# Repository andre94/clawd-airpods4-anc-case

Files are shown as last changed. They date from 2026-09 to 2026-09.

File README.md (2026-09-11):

# Clawd AirPods 4 ANC Case

**Open, editable CAD for a Clawd-inspired protective cover — not just an STL.**

[Italiano](docs/README.it.md) · [Print files](exports/v04-bottom-access/) ·
[Editable Blender source](models/clawd-airpods4-anc-v04-bottom-access.blend) ·
[Build from source](docs/BUILD.md) · [Licenses and credits](LICENSE.md)

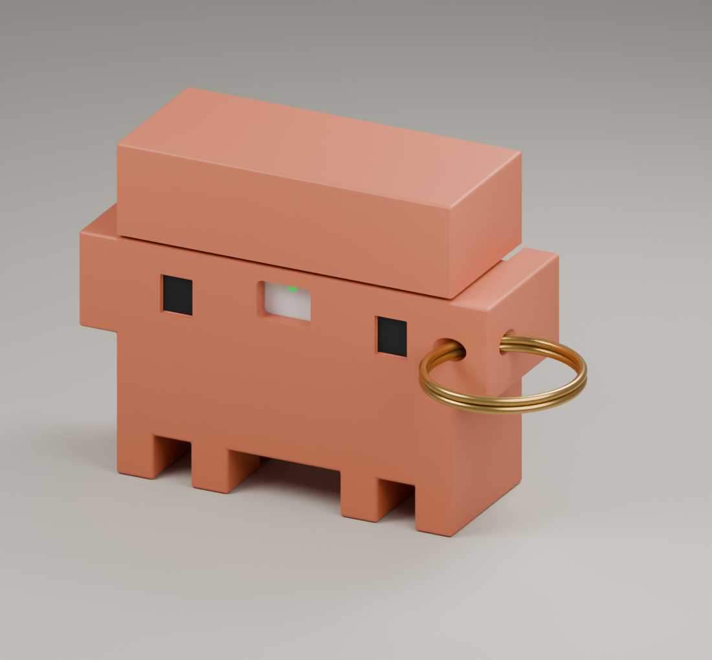
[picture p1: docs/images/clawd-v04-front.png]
Illustrative v04 render with terracotta finish and a reference metal split ring


> **v04-bottom-access — WORK IN PROGRESS.** No physical print or
> actual-device fit test has been completed. Digital mesh and surrogate
> clearance checks are not proof of fit, retention, charging performance or
> keyring strength. Do not treat this as a production-ready product or trust
> an untested cover to carry your AirPods. [Qualification checklist →](docs/QUALIFICATION.md)

v04 adds fuller wrap-around coverage and **five seats for separate soft retention
pads**. The pads are required trial hardware, not printed parts. Bare rigid shells
remain unretained. [Changes, pad guidance and digital checks →](docs/clawd-design-v04.md)

**11 September 2026 update:** removed the two bottom bridges between USB-C and
the side service windows. The lid and all other mesh geometry are unchanged.
Use the `v04-bottom-access` downloads, not the historical v03/v04 exports.
The `v0.4.0-alpha` tag remains the earlier baseline; no new release tag is created.
[Bottom-access changes and checks →](docs/clawd-bottom-access.md)

## Project links

Publication record for **11 September 2026**. The three website updates were
saved and their current file lists or active viewer checked after reloading:

| Platform | Link | Status and contents |
| --- | --- | --- |
| GitHub | [Source repository](https://github.com/andre94/clawd-airpods4-anc-case) | Public; canonical editable CAD, scripts and documentation. |
| GitHub Releases | [Releases and prereleases](https://github.com/andre94/clawd-airpods4-anc-case/releases) | v0.4.0-alpha is the original baseline, before the bottom-access update on main. Earlier releases remain historical artifacts. |
| Printables | [Model files](https://www.printables.com/model/1837773-clawd-airpods-4-anc-case-open-cad-v04-wip/files) | Published v04-bottom-access: two STLs, two-object 3MF and editable Blender file. Old downloads replaced; gallery renders kept. |
| Sketchfab | [Interactive 3D viewer](https://sketchfab.com/3d-models/clawd-airpods-4-anc-case-open-cad-v04-wip-1aea2f19414b48d38c48bbdb90f80ad6) | New bottom-access GLB activated. Downloadable visualization, not a print file. |
| Thingiverse | [Model files](https://www.thingiverse.com/thing:7407403/files) | Saved v04-bottom-access: two STLs, two-object 3MF and source ZIP. Displays the Work in Progress banner, not an unpublished-draft banner. |

Publication does not mean physical validation. Existing gallery renders were
kept; they do not show the underside change. Original v03/v04 files remain in
Git history and their versioned repository folders, not the current site downloads.

## What it is

A two-piece, removable outer cover for the **existing AirPods 4 with Active
Noise Cancellation charging case**. It is not a replacement charging case,
electronics project or certified protective accessory.

- Clawd-inspired blocky body, four legs and recessed eyes.
- Separate slip-on body and lid; no positive device or lid lock is claimed.
- Rear `andreabalbo.com` pixel engraving, nominally 1.0 mm deep.
- A rounded, diagonal Ø4 mm bore on the viewer-right block for a metal split ring.
- Fuller rear wrapping with shaped hinge relief, a bounded front window,
  and joined USB-C / side service openings.
- Five compliant-pad seats: two body sides, two lid sides and one lid roof.
- Terracotta/orange with black eyes is a finish reference, not a matched material color.

Only the **two plastic parts** are print deliverables. The AirPods model, eye
paint previews, pad previews, metal ring, floor, cutters and source assets must not be printed.
The ring shown is illustrative; no hardware is included or specified as load-rated.

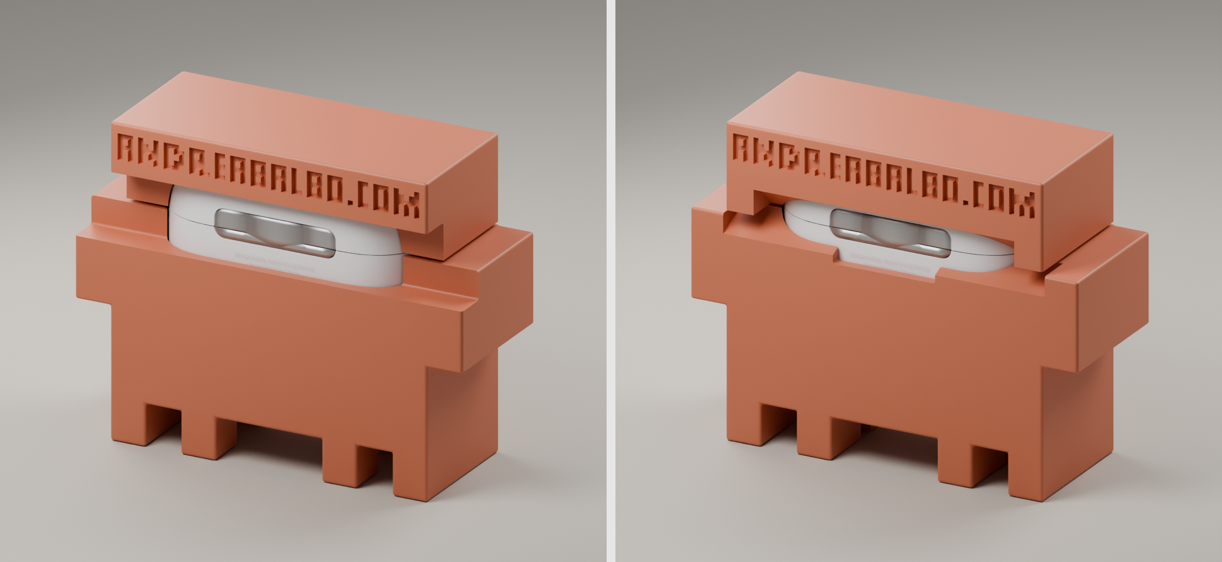
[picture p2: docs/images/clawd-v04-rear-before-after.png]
v03 on the left and v04 on the right, showing fuller rear coverage with hinge clearance


All gallery images are CAD renders, not photographs of a tested print.

## Start here

1. Read [PRINTING.md](docs/PRINTING.md) before paying for a print.
2. Download **one body + one lid** from `exports/v04-bottom-access/`.
   Use **either the two STLs or the two-part 3MF**, not both sets.
3. Select millimetres and 100% scale. Ask your printer to review walls, cavity
   tolerance, engraving and keyring geometry for its specific process.
4. Obtain separate compliant pads. The initial 0.80 mm soft-foam trial thickness
   must be tuned and tested; neither retention force nor adhesive safety is qualified.
5. Print an unpainted prototype first. Validate it on the real device before
   paying for color finishing or treating it as a usable carrying accessory.

| Item | Nominal CAD dimensions, mm |
| --- | --- |
| Body STL | 75.78 × 26.90 × 42.40 |
| Lid STL | 62.00 × 26.90 × 16.50 |
| Closed plastic assembly, excluding hardware | 75.78 × 26.90 × 59.60 |
| Cavity clearance relative to visual surrogate | 0.35 normal offset |
| Local pad-seat normal gap relative to surrogate | 0.65 |
| Keyring bore | Ø4.00 |

Dimensions are CAD values, not measured finished parts or toleranced drawings.
The 3MF contains meshes and explicit millimetre units, **not a validated printer profile**.

## Source and remixing

Open `models/clawd-airpods4-anc-v04-bottom-access.blend` in Blender **5.2.1 LTS**
(the version used for this update). The file retains print parts, masters, cutters, fit-check
parts, credited visual references and presentation objects in named collections.
One Blender coordinate unit represents 1 mm; scene `scale_length` is 0.001.

The Python construction history and JSON parameters are included. A clean
rebuild needs Blender and Python, not Codex, Claude Code or a running MCP server:

```sh
python3 tools/rebuild.py --blender /path/to/blender --output /path/to/new-empty-build
/path/to/blender --background /path/to/new-empty-build/models/clawd-airpods4-anc-v04.blend \
  --python-exit-code 1 --python /path/to/new-empty-build/tools/export_clawd_bottom_access.py
```

The first command rebuilds the original v04 baseline; the second applies and
exports the approved bottom-access update in that new build directory.
See [BUILD.md](docs/BUILD.md) for the construction-stage dependencies,
supported lettering and reproducibility limits. Editing JSON does **not** update
the already-exported meshes automatically. Regenerate and revalidate changes.

## Contribute

Useful contributions include measured-device fit reports, printer/process
tolerance results, non-destructive retention improvements, keyring testing,
lettering improvements and accessible printing instructions. Use the issue
templates and [contribution guide](CONTRIBUTING.md). Failed prototypes are useful
data when material, process, scale and exact revision are recorded.

Please do not upload restricted reference assets, proprietary CAD, personal
shipping details, supplier correspondence or someone else's unlicensed designs.

## Open licensing and attribution

- **CAD, parameters, documentation and renders:** CC BY-SA 4.0 for our contributions.
- **Python tools and CI:** MIT.
- **Original Clawd and AirPods source assets:** CC BY 4.0, with author credits.

Both project licenses permit commercial reuse under their terms. That does not
grant trademark or endorsement rights. This is **unofficial fan work**, not an
Apple or Anthropic product. Read [LICENSE.md](LICENSE.md) and preserve
[THIRD_PARTY_NOTICES.md](THIRD_PARTY_NOTICES.md), including the credits to
**akmiller01** and **Falah3D**. Non-open donor-case files are excluded from this
repository, the public blend and the rebuild dependencies.

Designed by [Andrea Balbo](https://andreabalbo.com), with AI-assisted Blender
scripting and modelling. Geometry checks are automated; physical validation is
still a human, real-device task. The license does not provide a warranty.

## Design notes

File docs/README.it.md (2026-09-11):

# Clawd AirPods 4 ANC Case

Custodia protettiva esterna, in due parti, per il case di ricarica **AirPods 4
con ANC**. È un progetto fan-made ispirato a Clawd, non un prodotto Apple o
Anthropic e non un sostituto del case elettronico originale.

**v04-bottom-access: prototipo non ancora verificato fisicamente.** I controlli
digitali non garantiscono dimensioni finite, tenuta del coperchio, ricarica o
resistenza del foro. Non affidargli il trasporto degli AirPods prima delle prove.

Aggiornamento dell'11 settembre 2026: rimossi i due ponti inferiori tra USB-C e
le finestre laterali. Coperchio e tutte le altre geometrie restano invariati.
Il tag `v0.4.0-alpha` conserva la versione precedente; non viene creato un nuovo
tag. [Modifiche e controlli](clawd-bottom-access.md).

## Link del progetto

Registro dell'**11 settembre 2026**: aggiornamenti salvati e verificati sulle
tre piattaforme, con nuovi file `v04-bottom-access` e rendering esistenti mantenuti.

| Piattaforma | Link | Stato e contenuti |
| --- | --- | --- |
| GitHub | [Repository sorgenti](https://github.com/andre94/clawd-airpods4-anc-case) | Pubblico; CAD modificabile, script e documentazione di riferimento. |
| GitHub Releases | [Release e prerelease](https://github.com/andre94/clawd-airpods4-anc-case/releases) | v0.4.0-alpha resta la versione precedente, prima dell'aggiornamento su main. |
| Printables | [File del modello](https://www.printables.com/model/1837773-clawd-airpods-4-anc-case-open-cad-v04-wip/files) | Pubblicati due STL, 3MF e Blender aggiornati; vecchi download sostituiti. |
| Sketchfab | [Visualizzatore 3D interattivo](https://sketchfab.com/3d-models/clawd-airpods-4-anc-case-open-cad-v04-wip-1aea2f19414b48d38c48bbdb90f80ad6) | Nuovo GLB attivato. Non è un file per la stampa. |
| Thingiverse | [File del modello](https://www.thingiverse.com/thing:7407403/files) | Salvati due STL, 3MF e ZIP sorgenti aggiornati. La pagina mostra Work in Progress, non il banner di bozza non pubblicata. |

La pubblicazione non equivale a una verifica fisica. I rendering esistenti non
mostrano la modifica inferiore. Le versioni precedenti restano nello storico Git.

## Cosa scaricare

- Un corpo e un coperchio da `exports/v04-bottom-access/`.
- Scegliere i due STL **oppure** il 3MF contenente entrambi: non stampare duplicati.
- Unità millimetri, scala 100%. Il 3MF non contiene un profilo macchina validato.
- Il file Blender modificabile è in `models/`; parametri e script sono inclusi.

Corpo: circa **75,78 × 26,90 × 42,40 mm**; coperchio: **62 × 26,90 × 16,50 mm**.
Il foro portachiavi diagonale ha diametro nominale 4 mm. L'incisione
`andreabalbo.com` è profonda nominalmente 1 mm. Dispositivo e anello nei rendering
sono riferimenti visivi, non pezzi da stampare.

## Novità v04 e ritenzione

Maggiore copertura posteriore con scarico sagomato per la cerniera, finestra
frontale delimitata e aperture USB-C/laterali ora collegate. Non è una
custodia sigillata o impermeabile. Sagoma, incisione e foro restano invariati.

Servono **cinque inserti morbidi separati**, non stampati: due sul corpo, due
ai lati del coperchio e uno nel tetto. Le sedi hanno un gioco normale nominale
di 0,65 mm. Schiuma di silicone morbida da 0,80 mm è solo uno spessore iniziale
da provare, non una specifica verificata. Senza inserti i gusci rigidi restano
privi di ritenzione. Se necessario, valutare un inserto biadesivo rimovibile nel
tetto, dopo aver verificato compatibilità e rimozione; niente colla permanente.

Il controllo digitale di 116 posizioni da 0 a 115° non rileva collisioni con il
simulacro e gli inserti illustrativi. **Non è una prova fisica di apertura senza
attrito né di tenuta.** [Dettagli v04](clawd-design-v04.md).

## Come procedere

Prima un prototipo non verniciato, poi eventuali correzioni e finitura colorata.
Far valutare al fornitore materiale, spessori, tolleranze finite e resistenza
dell'attacco. Il PA12 non caricato MJF/SLS è un candidato da valutare, non una
specifica già qualificata. FDM, resina e TPU non sono automaticamente equivalenti.

Verificare sul dispositivo reale inserimento, rimozione, ritenzione, apertura,
accesso USB-C, altoparlante, comandi e ricarica. Il foro sostiene soltanto il corpo
esterno: **non blocca il case AirPods né il coperchio della cover**. Per le prove
di trazione usare prima un guscio vuoto o un simulacro, non gli AirPods.

Guide: [stampa](PRINTING.md), [prove fisiche](QUALIFICATION.md),
[ricostruzione da sorgenti](BUILD.md), [contributi](../CONTRIBUTING.md).

## Licenze

CAD, parametri, documentazione e rendering originali/adattati: **CC BY-SA 4.0**.
Script e workflow: **MIT**. Gli asset originali di akmiller01 e Falah3D conservano
**CC BY 4.0**, con attribuzione. Le licenze ammettono anche riuso commerciale alle
loro condizioni, ma non attribuiscono diritti sui marchi né implicano approvazione
dei produttori. Leggere [licenze](../LICENSE.md) e
[crediti completi](../THIRD_PARTY_NOTICES.md).

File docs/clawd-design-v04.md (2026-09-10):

# Clawd AirPods 4 ANC — v04 coverage and pad-retention prototype

10 September 2026. **Unvalidated physical prototype, not a production release.**

## Decision

The concern about the separate top cap is justified: v03 had a nominal
0.35 mm clearance cavity, a broad rear opening and no defined retention
hardware. Covering more of the device improves enclosure and provides more
supported contact area, but adding rigid material alone does not create grip.

The linked [Spigen Rugged Armor listing](https://www.amazon.it/dp/B0BC2B91VF),
checked on 10 September 2026, describes a two-piece **TPU** cover for **AirPods
Pro 2**, not a rigid PA12 cover for AirPods 4. Its fuller coverage is a useful
reference, but its dimensions and flexible fit cannot be copied directly.
The Clawd target remains **AirPods 4 with ANC**, using the existing calibrated
50.1 × 21.2 × 46.2 mm visual surrogate, not measured OEM CAD.

v04 keeps the two-shell architecture and the stock device hinge. It adds
fuller wrap-around coverage and deliberately specifies separate soft pads
instead of pretending that a loose hard-plastic cap will retain itself.

## Geometry changes

| Feature | v04 change |
| --- | --- |
| Lid | Extends the rear skirt outside the local hinge region; front, roof and side coverage remain |
| Rear body | Restores material outside the local hinge window, then clears the actual planned opening motion |
| Rear hinge window | 20 mm central construction width instead of a full-width cut; additional shaped motion clearance remains |
| Front | Bounded 10 × 7 mm rounded LED/pairing window, centred at Z 28.3 mm; a solid bridge now runs above it |
| Bottom | 14 × 8 mm USB-C window and two 6 × 4 mm speaker-access windows at X ±13 mm, replacing the 36 × 10 mm opening |
| Lid retention | Two side-pad seats plus one 16 × 7 mm roof-pad seat |
| Body retention | Two side-pad seats |
| Preserved | Clawd silhouette, eye recesses, 1 mm pixel branding, 4 mm diagonal keyring bore, nominal device calibration and 0.70 mm seam gap |

The rigid lid cannot extend uninterrupted across the entire rear seam: that
material would sweep into the charging-case body when opened. The rear cap
relief is derived from a 0.45 mm-expanded body envelope swept into lid
coordinates. Each section is clipped to the relevant rear region before
convex enclosure, avoiding an unnecessarily large cut across the cap. The
outer body is also relieved for the rear skirt. Construction samples are
0.5 degrees apart; verification separately checks 116 poses at 1-degree steps.

**This is fuller coverage, not a completely sealed case.** Functional hinge,
LED/tap, USB-C and speaker openings remain. No waterproof or impact rating is
claimed. The service windows are provisional and must be checked on the real
AirPods and charging cable; matching a visual asset does not validate access.

The closed printed envelope is unchanged. The body remains approximately
75.778 × 26.900 × 42.396 mm and the lid 62.000 × 26.900 × 16.504 mm.
Body and lid heights are separate part bounding boxes, not the assembled height.

## Retention pads — required, not printed

The cavities outside the seats retain the v03 nominal 0.35 mm clearance. The
seats use a nominal 0.65 mm normal offset, approximately 0.30 mm deeper than
the original cavity, to accommodate compliant pads. **Without pads, these
recesses do not improve grip and the bare shells remain unretained.**

| Seat | Quantity | Nominal footprint / position |
| --- | --- | --- |
| Body side | 2 | 8 mm in Y × 8 mm in Z; Z 18–26 mm |
| Lid side | 2 | 8 mm in Y × 5 mm in Z; Z 39.2–44.2 mm |
| Lid roof | 1 | 16 mm in X × 7 mm in Y; follows the inner roof contour |

Use supplier-approved, soft, non-marking silicone foam or equivalent compliant
material. **0.80 mm uncompressed thickness is an initial sample, not a finished
fit specification.** It suggests roughly 0.15 mm compression against a nominal
0.65 mm normal gap, but local curvature, adhesive backing, material behaviour,
device geometry and print tolerances all change the result. Footprints are
projected design dimensions, not flattened cutting patterns for curved pads.

Pads initially bond to the cover and grip the device by friction. If a physical
test shows insufficient lid retention, the roof seat can accommodate a
finish-compatible **removable double-sided pad**. Qualify its removability and
surface compatibility first; do not use permanent glue or force the device in.
There is no rigid snap feature against the unmeasured Apple seam, no latch,
no retention-force prediction and no secure-carrying claim.

The five charcoal objects in the Blender file are illustrative seated pad
envelopes with a small display clearance. They are **not uncompressed foam
CAD, print parts or a deformation simulation**. The two metal ring coils are
also display-only. Print exports contain only the two rigid shells.

## Digital checks

- Both final print meshes are closed, single-component and consistently
  oriented, with positive volumes, no loose geometry, no non-manifold edges
  and no non-adjacent triangle-overlap candidates in the mesh screen.
- Closed shell/device intersection volumes pass, as do 66 sampled axial
  insertion positions per rigid shell. Insertion with real compressed pads
  is not simulated.
- The dense motion screen checks 0–115 degrees inclusive at 1-degree steps,
  including the rigid lid and seated pad previews against the body, body-pad
  previews, charging-case body surrogate and positioned reference ring.
  It reports no surface collisions. Real hinge geometry, continuous motion,
  elastic behaviour and hardware articulation remain unqualified.
- Nine axis-aligned rays per pad seat give body-side gaps of approximately
  0.650–0.665 mm, lid-side gaps of 0.702–0.822 mm and roof gaps of 0.650–0.662 mm.
  Axis gaps are not normal pad thicknesses. The smallest sampled seat backing
  is approximately **2.100 mm at the roof**; this is not a global wall minimum.
  Measurement uses zero BVH inflation and avoids shared-facet sampling points.
- The v03 insertion cutters, calibration references, branding cutter and
  keyring cutter retain their geometry digests. The new shells reuse them.
- STL round-trip dimensions and topology pass at one coordinate unit per mm.
  The 3MF explicitly declares millimetres and contains exactly two objects.
- All previous `.blend` models and original reference-input hashes are unchanged.
  No external references are reported missing in the saved model.

A separate 0.5 mm orthographic grid screen measures **projected exposed
surrogate area**, excluding pads. It is not total surface coverage or a
protection rating:

| View | v03 exposed area | v04 exposed area | Reduction |
| --- | ---: | ---: | ---: |
| Front | 118.50 mm² | 69.25 mm² | 41.6% |
| Rear | 562.00 mm² | 343.00 mm² | 39.0% |
| Bottom | 359.25 mm² | 158.25 mm² | 55.9% |

## Files and reproduction

- Editable model: `models/clawd-airpods4-anc-v04.blend`.
- Parameters: `models/clawd-v04-parameters.json`.
- Revision builder: `tools/revise_clawd_coverage.py`.
- Render script: `tools/render_clawd_coverage.py`.
- Print prototypes and briefing: `exports/clawd-v04/clawd-prototype/`.
- Machine-readable mesh, export and coverage checks: `exports/clawd-v04/qa/`.
- Release renders: `docs/images/`; the rear comparison is **v03 left,
  v04 right**. `pad-seats` is an exploded, device-hidden view, not an operating
  hinge position. Colour and hardware are illustrative.

Use `tools/rebuild.py` as described in [BUILD.md](BUILD.md) to reconstruct the
entire history without MCP. The v04 builder opens the saved v03 file in a separate
background Blender process. It refuses live interactive scenes, checks millimetre units
and refuses to overwrite an existing v04 unless its exact expected SHA-256 is
supplied. It preserves archived v03 shells inside the new file. The old fit-check
pair remains historical context and is **not** a v04 pad-fit coupon or export.

The render script opens v04 in background, regenerates its own presentation
scene and does not save over the editable model. The live Blender bridge was
unavailable during this revision; no live scene or global preferences changed.

## Physical qualification before carrying or ordering

1. Obtain written supplier acceptance for the new files, unfilled MJF PA12,
   finished cavity accuracy, new rear contours, pad seats and service windows.
   Do not scale, automatically thicken or silently repair the model.
2. Print one unpainted pair. Inspect and depowder all openings. Check the actual
   device and cable before adding pads; never force a tight fit.
3. Measure the printed seat gaps and trial compliant pads of suitable thickness.
   Verify device finish compatibility and removal. Excessively thick pads can
   overload the lid hinge or make the case difficult to remove.
4. Test body and cap retention separately, including repeated opening, closing,
   removal and ordinary handling over a soft surface. Qualify any removable roof
   adhesive only if needed. Do not infer retention from the digital mesh check.
5. Check full opening, earbud removal, the LED and pairing/reset taps, USB-C
   connector moulding, ANC speaker audibility and Qi/Apple Watch charging,
   including attachment, alignment and temperature with pads installed.
6. Test the keyring anchor with an empty case or suitable dummy. **Do not carry
   the real AirPods by the ring until body retention, cap retention and anchor
   behaviour have all been physically qualified.** No load rating is provided.

v04 has not been uploaded to a printer, quoted, accepted or ordered.
Earlier v02/v03 quote or automatic acceptance results do not transfer to it.

The public Blender copy removes restricted donor and donor-derived archived
objects without changing the v04 print geometry. `publication-audit.json`
records the unchanged geometry digests; `manifest.json` records public file hashes.
`final-review.json` records the pre-publication working-scene hash, not the
sanitized public Blender file hash. Publication is not physical qualification.

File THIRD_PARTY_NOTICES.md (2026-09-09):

# Third-party notices and provenance

Source pages and license links checked on 9 September 2026. Attribution is not
an assertion that the original uploaders control every depicted brand right.

## Clawd silhouette — akmiller01

- Work: [Simple Claude Code Mascot - Clawd](https://www.printables.com/model/1655582-simple-claude-code-mascot-clawd).
- Author: [akmiller01](https://www.printables.com/@akmiller01_232084).
- License: [Creative Commons Attribution 4.0 International](https://creativecommons.org/licenses/by/4.0/).
- Original included at `assets/reference/clawd.stl` and in the `CLAWD_ORIGINAL`
  collection of the editable assembly.
- Provenance check: the original local file's download-origin URL exactly
  matches the target of the `clawd` STL download button on that model's Files
  page. It is the 6,284-byte file, not the separate `clawd_singlecolor` variant.
- Modifications: extracted and proportionally adapted silhouette, new depth,
  rounded edges, split body/lid, cavity and service cuts, rebuilt eye recesses,
  custom rear lettering and diagonal keyring bore.

## AirPods 4 visual reference — Falah3D

- Work: [AirPods 4](https://sketchfab.com/3d-models/airpods-4-e44730974131402eb496352cab19c82e).
- Author: [Falah3D / 3dFalah](https://sketchfab.com/3dFalah).
- License: [Creative Commons Attribution 4.0 International](https://creativecommons.org/licenses/by/4.0/).
- Original FBX and textures are included under `assets/reference/airpods-4/`;
  imported objects are in `AIRPODS_VISUAL_REFERENCE_NOT_METROLOGY`.
- Identification evidence: matching title, original FBX format, 16 February
  2026 file date, approximately 7 MB source bundle and the published 54.3k
  vertices / 99.2k triangles (local import: 54,281 / 99,248). A fresh archive
  byte-for-byte comparison was not available because the browser blocked its
  download. This identification is documented rather than presented as a
  verified upstream checksum.
- Modifications: close the visual lid pose; calibrate overall dimensions to
  published nominal dimensions; derive convex body/lid envelopes and offset
  cavities; position and re-material selected geometry for illustrative renders.
- This is not Apple engineering CAD, metrology, a fit guarantee or certification.

## Studied but excluded — Generic Makerspace

The private reference study also inspected *Milk Crate Airpods 4 Case* and
*Retro Gameboy Airpods 4 Case* by Generic Makerspace. Both supplied 3MF files
declare **Standard Digital File License**, not an open license.

Those 3MF files, STL archives, extracted donor meshes, reference-study blend,
creator images and slicer profiles are **not included** here. Donor body/lid
objects are removed from the public Blender copy. The public reconstruction
imports only the two CC BY assets above; no donor package is required. The
cover's cavity is derived from the credited AirPods visual reference, not from
the restricted case meshes.

## Tools and brand names

Blender is separately licensed software. Its source, binaries and the Blender
Lab MCP server are not vendored here. The project uses Blender's Python API;
the optional MCP connection is a development convenience, not a build dependency.

Clawd is a Claude Code mascot reference. This is unofficial fan work, not
affiliated with or endorsed by Anthropic or Apple. Project licenses do not
grant rights in their names, trademarks or other rights outside our control.

Suggested credit when sharing an image or adaptation:

> Clawd AirPods 4 ANC Case by Andrea Balbo, CC BY-SA 4.0. Adapted from
> “Simple Claude Code Mascot - Clawd” by akmiller01 (CC BY 4.0); AirPods visual
> reference by Falah3D (CC BY 4.0). Unofficial, physically unvalidated prototype.

Include the source and license links above with that credit, and identify your
own changes. Reference-only hardware and device geometry are not print parts.

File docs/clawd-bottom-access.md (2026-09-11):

# Bottom-access update — 11 September 2026

The `v04-bottom-access` files replace the previous website downloads. The
original `v0.4.0-alpha` tag remains unchanged; this update does not create a tag.

## Geometry

Removed the two narrow body bridges between the USB-C opening and the side
service windows using rounded Boolean cutters:

| Side | Minimum XYZ, mm | Maximum XYZ, mm | Radius, mm |
| --- | --- | --- | --- |
| Left | −11.5, −2, −15 | −5.5, 2, 8 | 0.8 |
| Right | 5.5, −2, −15 | 11.5, 2, 8 | 0.8 |

The cuts overlap the existing windows, joining them without widening the outer
ends. The body envelope, lid and all other mesh geometry remain unchanged.
About 59.597 mm³ of material is removed. The credited visual device model is
not measured OEM CAD; visible access is not proof of real-device alignment.

## Files and checks

- [Current printable pair and GLB](../exports/v04-bottom-access/).
- [Editable source](../models/clawd-airpods4-anc-v04-bottom-access.blend).
- [Patch/export script](../tools/export_clawd_bottom_access.py).
- [Digital validation report](../exports/v04-bottom-access/validation.json).
- [Build instructions](BUILD.md) and [printing guidance](PRINTING.md).

The public source was generated from the sanitized, unanimated v04 baseline.
The body exactly matches the approved local study geometry:
`bb031bed17fe1cbfba8442a1411f668d860277779b1489c44ae3fb4ee46e9959`.
It remains one closed oriented component with positive volume, no loose vertices,
degenerate faces or nonadjacent triangle-overlap candidates. All 18 sampled
vertical rays through the two removed bridges are unobstructed.

Both STLs pass millimetre-scale round-trip checks. The 3MF has two mesh objects
and explicit millimetre units. The viewer has four meshes: body, lid and two
paint indicators; no device, pads, ring or cutters. Its combined glTF-axis bounds
are 75.78 × 59.60 × 26.90 mm.

Existing uploaded gallery renders were kept. The sites may regenerate previews
associated with replaced model files. No actual print or physical test has been
performed: check alignment, cable clearance, acoustics, charging, retention,
finish compatibility and strength before use.

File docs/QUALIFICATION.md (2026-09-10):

# Physical qualification — pending

No real-device or physical-print test has been completed for this release.
The downloaded AirPods visual model is not measured OEM CAD. Published Apple
overall case dimensions (50.1 × 21.2 × 46.2 mm) do not specify local contours,
hinge location, opening forces or manufacturing tolerances.

## Current evidence

- The two release meshes have closed, consistently oriented geometry and one
  connected component each in the recorded digital checks.
- Discrete surrogate-based insertion and hinge sweeps pass the recorded checks.
- v04 passes 116 hinge poses from 0–115° at 1° intervals, including illustrative
  seated pads. This is a collision screen, not proof of frictionless opening,
  real hinge alignment, foam deformation or a continuously swept clearance.
- The keyring envelope check is a geometric screen, not a threading simulation,
  minimum-wall certification, fatigue test or load rating.
- No supplier's approval, physical fit, protective performance, drop resistance,
  wireless charging behavior or hardware retention is established by those checks.

## Record for each prototype

Record exact release/commit and file SHA-256, printer/provider, process, material,
orientation, dimensional settings, finish and any post-processing. Use measured
values when available; mark visual estimates explicitly. Never put addresses,
phone numbers, invoices, order numbers or private correspondence in a public issue.

For v04, also record pad material, uncompressed thickness, adhesive backing,
placement, removability and changes after compression/wear. The five pad seats
and suggested 0.80 mm starting trial do not constitute a tested retention system.

- [ ] Inspect the empty print for sharp edges, loose powder/supports and cracks.
- [ ] Confirm overall dimensions and local clearances; check cavity condition.
- [ ] Trial gentle insertion/removal without force or leverage on connectors.
- [ ] Verify body retention and **separate lid retention** independently.
- [ ] Check pad surface compatibility, compression, adhesive residue and safe
      removal; test a removable roof bond separately if one is needed.
- [ ] Check full lid opening, hold-open behavior and earbud removal by hand.
- [ ] Check the actual USB-C plug without loading the charging port.
- [ ] Verify status LED visibility and pairing/reset front-tap operation.
- [ ] Verify ANC Find My speaker audibility through the cover.
- [ ] Check Qi and Apple Watch charging alignment, attachment and temperature;
      stop on unusual heating, interrupted charging or other abnormal behavior.
- [ ] Check the actual split ring's wire dimensions, threading and articulation
      without scratching or stressing the plastic.
- [ ] Evaluate pull, twist, snag and wear with an **empty cover or dummy first**.
      Do not use valuable electronics for unqualified load or drop tests.
- [ ] Recheck retention after wear, finishing and any removable liner adjustment.

The keyring attaches only to the outer body. It does not lock the AirPods case
inside it or secure the separate cover lid. There is **no rated carrying load**.
Passing one sample does not establish reliability for different materials or
printers. Document failures and revisions rather than silently scaling files.

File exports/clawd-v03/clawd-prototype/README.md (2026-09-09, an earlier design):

# v03 prototype print files — physically unvalidated

Print one body and one lid. Use **either both STLs or the two-part 3MF**; do not
order duplicate parts by uploading all three files. Units are millimetres at
100% scale. The 3MF is mesh-only, not a qualified slicer profile.

- Body: 75.78 × 26.90 × 42.40 mm.
- Lid: 62.00 × 26.90 × 16.50 mm.
- No device, ring, paint or assembly hardware is included.

Read [printing guidance](../../../docs/PRINTING.md) and the
[physical qualification checklist](../../../docs/QUALIFICATION.md) before
ordering. Ask your printer to assess cavity tolerances, thin walls, engraving
and keyring strength. First print unpainted; fit and retention are untested.
An untested cover must not be relied on to carry the device.

CAD adaptations by Andrea Balbo, CC BY-SA 4.0; upstream Clawd by akmiller01 and
AirPods visual reference by Falah3D, CC BY 4.0. Preserve
[third-party notices](../../../THIRD_PARTY_NOTICES.md) and
[license terms](../../../LICENSE.md). Unofficial fan work; no brand rights granted.

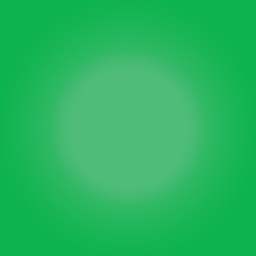
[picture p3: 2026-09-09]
assets/reference/airpods-4/textures/DGBEWepXmsFLatr.png

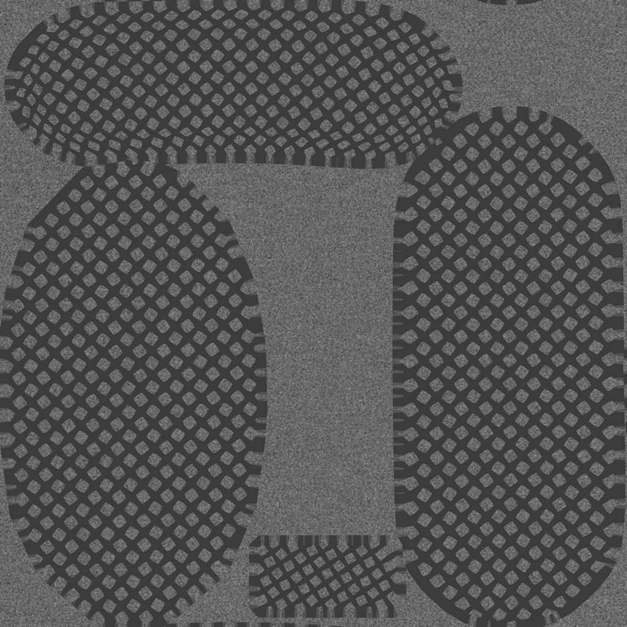
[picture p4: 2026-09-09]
assets/reference/airpods-4/textures/hzRAhqrsyMepKLY.jpg

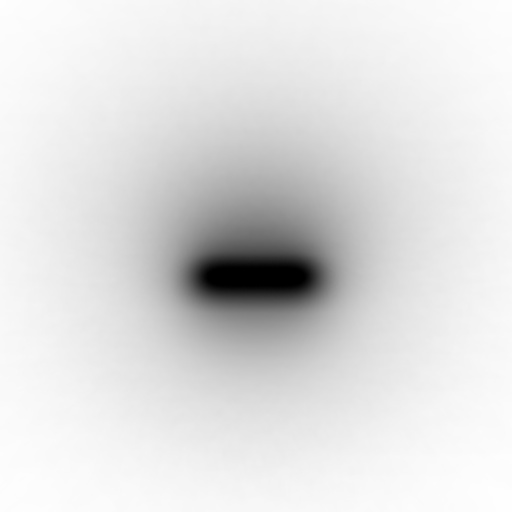
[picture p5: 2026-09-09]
assets/reference/airpods-4/textures/internal_ground_ao_texture.jpeg

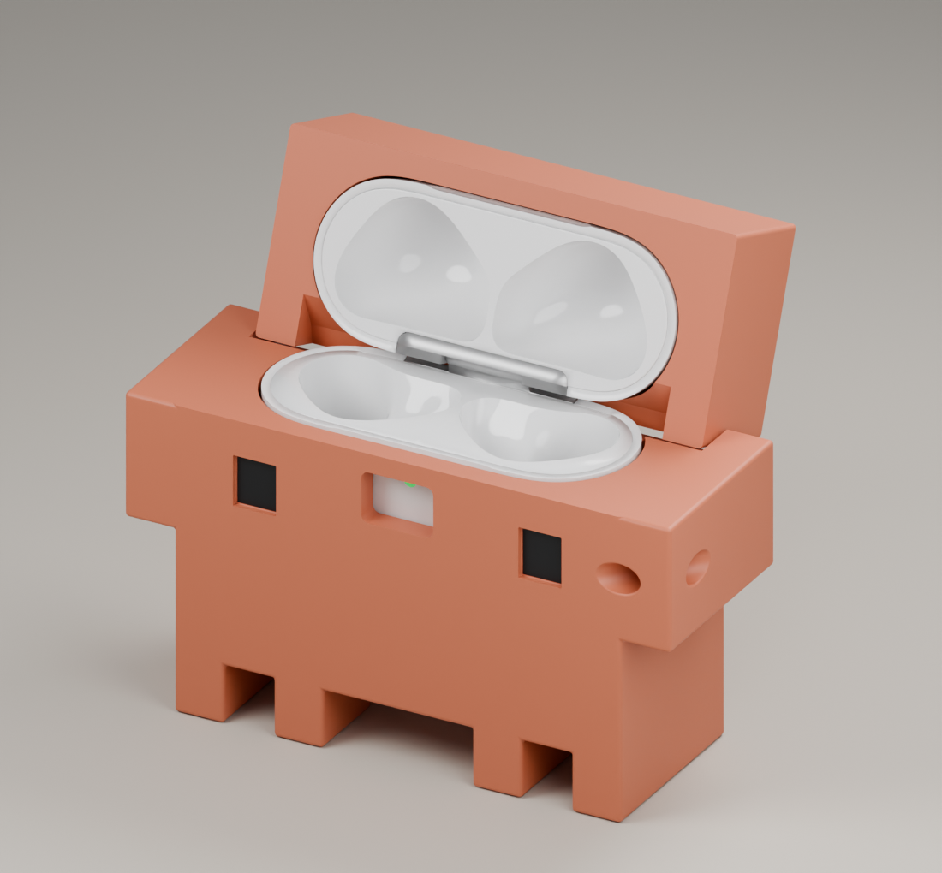
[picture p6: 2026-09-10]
docs/images/clawd-v04-open.png

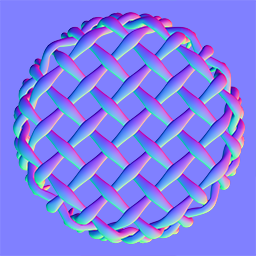
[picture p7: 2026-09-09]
assets/reference/airpods-4/textures/IcYzXMIntnUGVkS.png

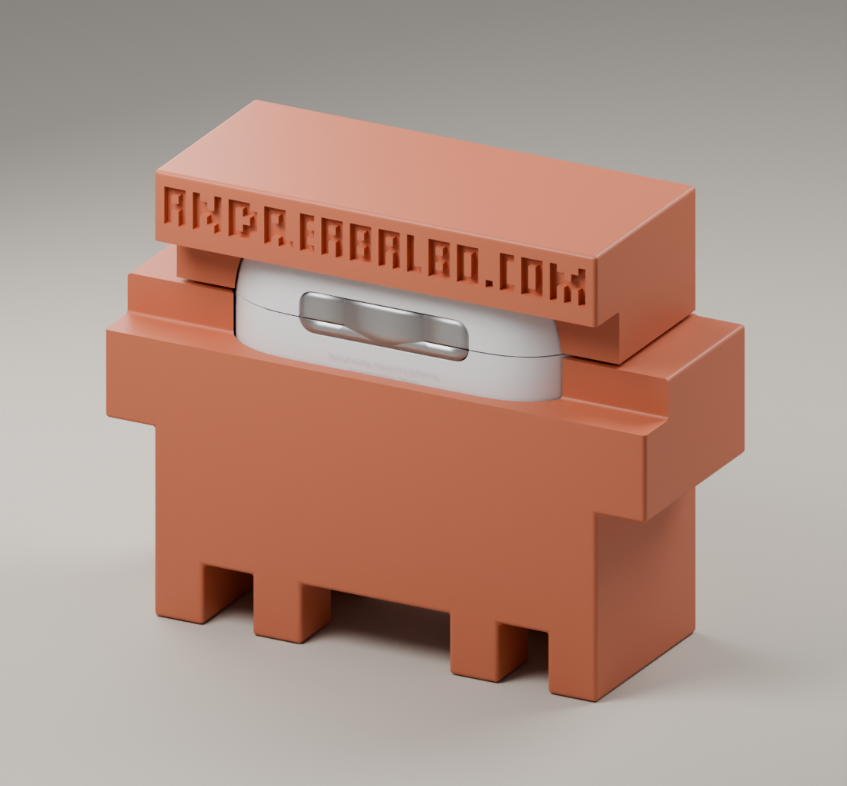
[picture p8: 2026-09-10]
docs/images/clawd-v04-rear-v03-baseline.png

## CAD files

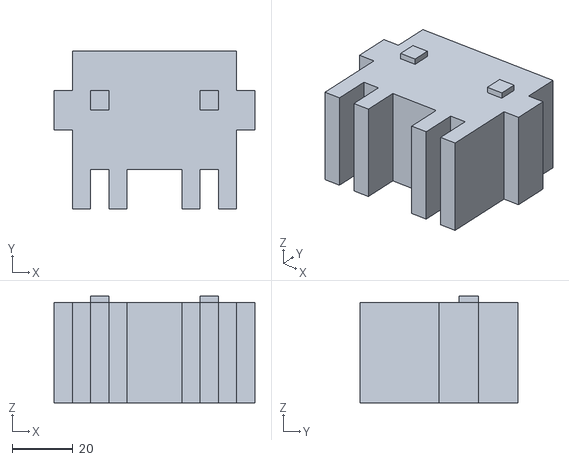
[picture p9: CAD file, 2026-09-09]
assets/reference/clawd.stl
66.0 x 52.0 x 35.0

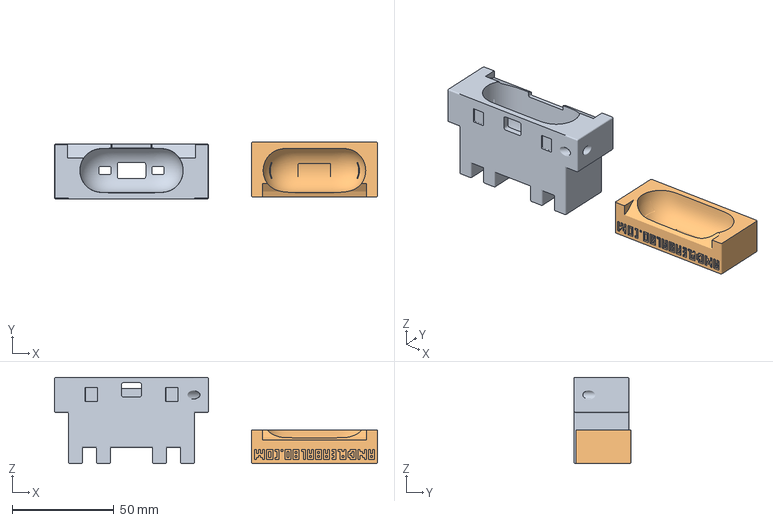
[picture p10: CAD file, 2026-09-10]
exports/clawd-v04/clawd-prototype/clawd-prototype-pair-v04-mm.3mf
158.9 x 27.9 x 42.4 mm
CLAWD body - UNVALIDATED v04
CLAWD lid - UNVALIDATED v04

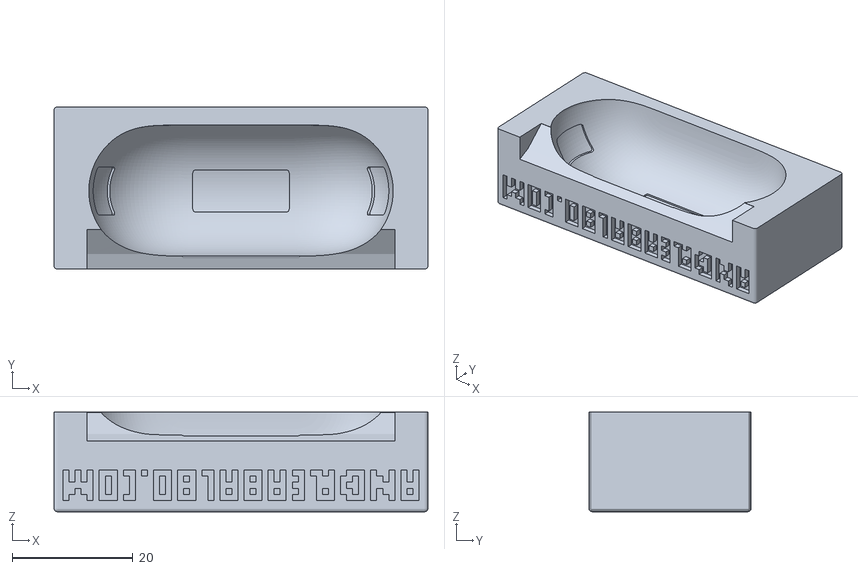
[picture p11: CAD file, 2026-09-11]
exports/v04-bottom-access/clawd-prototype-lid-v04-bottom-access-mm.stl
62.0 x 26.9 x 16.5

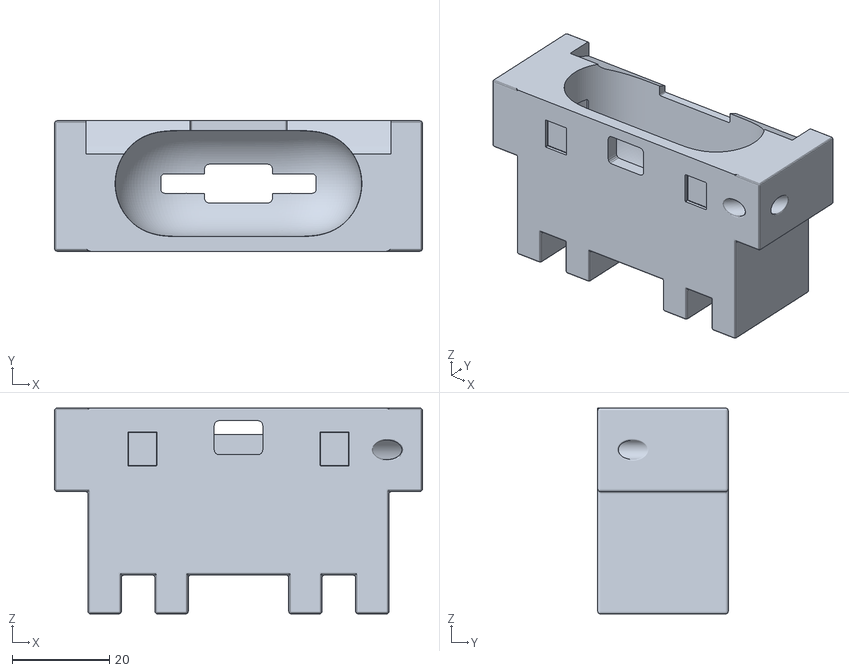
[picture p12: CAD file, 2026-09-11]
exports/v04-bottom-access/clawd-prototype-body-v04-bottom-access-mm.stl
75.8 x 26.9 x 42.4

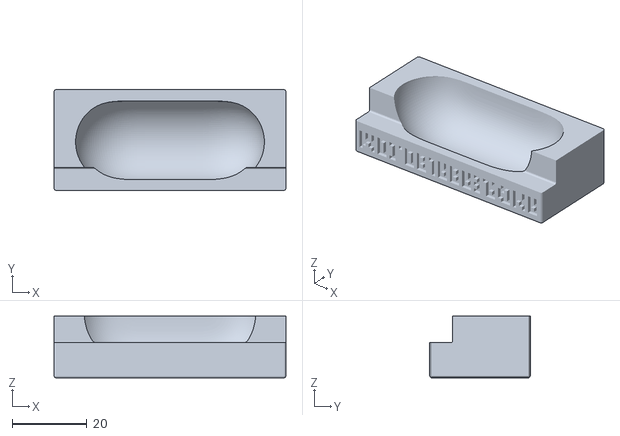
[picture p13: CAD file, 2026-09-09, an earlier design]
exports/clawd-v03/clawd-prototype/clawd-prototype-lid-v03-mm.stl
62.0 x 26.9 x 16.5

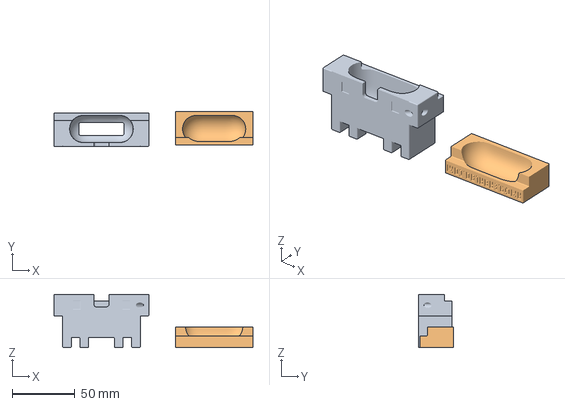
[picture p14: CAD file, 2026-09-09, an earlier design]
exports/clawd-v03/clawd-prototype/clawd-prototype-pair-v03-mm.3mf
158.9 x 27.9 x 42.4 mm
CLAWD body - UNVALIDATED v03
CLAWD lid - UNVALIDATED v03

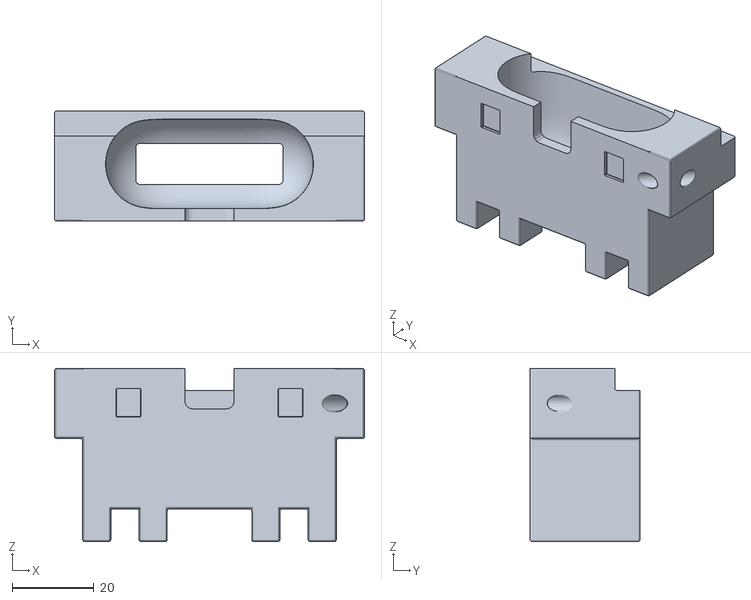
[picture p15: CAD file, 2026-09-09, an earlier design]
exports/clawd-v03/clawd-prototype/clawd-prototype-body-v03-mm.stl
75.8 x 26.9 x 42.4

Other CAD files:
exports/clawd-v04/clawd-prototype/clawd-prototype-lid-v04-mm.stl
exports/clawd-v04/clawd-prototype/clawd-prototype-body-v04-mm.stl
exports/v04-bottom-access/clawd-prototype-pair-v04-bottom-access-mm.3mf
models/clawd-airpods4-anc-v03.blend
models/clawd-airpods4-anc-v04-bottom-access.blend
models/clawd-airpods4-anc-v04.blend

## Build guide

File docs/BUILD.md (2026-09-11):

# Build and edit

## Current bottom-access update

The current editable model is `models/clawd-airpods4-anc-v04-bottom-access.blend`,
and current print/viewer files are in `exports/v04-bottom-access/`.
`v0.4.0-alpha` and the v04 files without this suffix are historical baselines.

The rebuild command below produces the v04 baseline in a new directory. Then
apply the bottom-access update using the script copied into that directory:

```sh
/path/to/blender --background /path/to/new-empty-build/models/clawd-airpods4-anc-v04.blend \
  --python-exit-code 1 --python /path/to/new-empty-build/tools/export_clawd_bottom_access.py
```

The script refuses to overwrite an existing bottom-access `.blend`. It verifies
the baseline geometry digest, removes two rounded bridges, matches the approved
study digest, checks that other meshes are unchanged, and exports/round-trip
checks the printable pair. The GLB contains only the body, lid and two paint
indicators in metre coordinates. No animated inspection pose is used for exports.

See [the bottom-access report](../exports/v04-bottom-access/validation.json)
and [design notes](clawd-bottom-access.md). This is digital validation only.

## Requirements

- Blender 5.2.1 LTS, including its Python API and FBX importer.
- Python 3.10+ for the orchestration script; standard library only.
- Source files included under `assets/reference/`, with CC BY 4.0 attribution.

Codex, Claude Code, Blender MCP, cloud credentials and a network connection are
not needed after downloading the repository. No restricted donor case is used.

## Rebuild without overwriting the downloaded release

```sh
python3 tools/rebuild.py --blender /path/to/blender --output /path/to/new-empty-build
```

On macOS, the Blender executable may be
`/Applications/Blender.app/Contents/MacOS/Blender`. The output path must not exist.
The command copies only credited source assets, Python tools and JSON parameters
to a new build directory, then starts separate background Blender processes.
It does not reset an interactive Blender scene or overwrite the release blend.

The sequence is:

1. Import the Clawd STL and AirPods FBX only; save a millimetre reference scene.
2. Hash the included inputs for later integrity checks.
3. Build the v01 cover from its JSON parameters and the source envelopes.
4. Rebuild the lid with the v02 robust pixel lettering.
5. Add the v03 diagonal keyring bore and run its digital validation/export gates.
6. Add the v04 wrap-around coverage, shaped hinge relief and compliant-pad seats;
   run the new hinge checks and export only the rigid body/lid shells.

Final outputs are in the new build's `models/` and `exports/clawd-v04/` folders.
The reconstruction can differ at the byte/triangulation level between Blender
versions; geometry, dimensions and validation results matter, not a promise of
bit-identical `.blend` or mesh files. A build success is not physical validation.

### Verified v04 clean rebuild

On 10 September 2026, Blender 5.2.1 LTS (build `9e2066aef7ef`) rebuilt v01 through
v04 using only the included CC BY reference assets. Both final v04 STLs were
byte-identical to the release meshes and the digital gates passed. See
[rebuild-validation.json](../exports/clawd-v04/qa/rebuild-validation.json).
The scene file itself need not be byte-identical. No physical test was performed.

### Historical v03 clean rebuild

On 9 September 2026, a clean rebuild using Blender 5.2.1 LTS (build
`9e2066aef7ef`) completed all digital gates using only the included CC BY
reference assets. Both final prototype STLs were byte-identical to the v03
release meshes. See [rebuild-validation.json](../exports/clawd-v03/qa/rebuild-validation.json)
for the recorded SHA-256 values. This result applies to that tested environment;
it does not promise identical results across Blender versions or physical fit.

## Parameter dependencies

- `models/clawd-v01-parameters.json`: source envelope dimensions, cavity offset,
  main body, openings, seam, reliefs and initial construction.
- `models/clawd-v02-parameters.json`: robust rear lettering revision.
- `models/clawd-v03-parameters.json`: final keyring bore and reference hardware.
- `models/clawd-v04-parameters.json`: fuller coverage, local access windows,
  swept hinge relief and compliant-pad seats.

Shared fields repeated in later files document the inherited design; changing
only a repeated v03 cavity field does **not** rebuild the v01 cavity with that
new value. Update the construction-stage parameter file and keep later metadata
consistent, then rebuild all stages. The pipeline is a construction history,
not yet a unified live-parametric CAD application.

The pixel lettering tool currently supports the lowercase characters in
`andreabalbo.com` only. Other text needs suitable glyph definitions and a width,
wall and non-manifold-contact review. Engraving dimensions must remain compatible
with the lid and the printer's feature limits.

## Blender collections

`01` contains the two final print parts. `02` is the calibrated visual surrogate;
`03` holds editable masters and cutters; `04` is finish preview; `05` is the
simplified fit-check pair, not the full Clawd prototype. Studio objects and
keyring hardware are presentation-only. Upstream source collections retain
their own CC BY license metadata. Restricted donor meshes are absent.
Collection `10` contains historical v03 shells for before/after renders, not
print exports. Collection `11` contains illustrative seated pads, not printable
foam parts. The old fit-check pair does not represent v04 retention.

## Renders

To regenerate the v04 views and v03/v04 rear comparison from a rebuilt model:

```sh
/path/to/blender --background /path/to/new-empty-build/models/clawd-airpods4-anc-v04.blend --python /path/to/new-empty-build/tools/render_clawd_coverage.py
```

Only body/lid print meshes should be exported for manufacture. Do not export all
scene objects. Mesh exports are millimetres; OBJ/STL tools may otherwise assume
metres. Do not change scene unit scale or apply another 1000× conversion blindly.

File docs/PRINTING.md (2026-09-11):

# Printing the v04-bottom-access prototype

**Not physically validated. Request a supplier-specific technical review before
ordering. An automatic quote or a watertight mesh is not manufacturing approval.**

## Quantity, units and orientation

Print one `clawd-prototype-body-v04-bottom-access-mm.stl` and one
`clawd-prototype-lid-v04-bottom-access-mm.stl` from `exports/v04-bottom-access/`,
or use the matching two-part 3MF. Do not
combine both options into an order. All dimensions are in mm at 100% scale.
The exported lid is reoriented for separate manufacture; the native blend
shows its assembled position. The printer should choose build orientation,
supports and finishing appropriate to its equipment.

No validated layer height, wall count, infill, support recipe or G-code is
provided. Machine-specific profiles would imply evidence we do not yet have.
Do not print the reference STL/FBX in `assets/` or all objects from the blend.

## Material and finishing

Unfilled PA12 nylon by MJF or SLS is a candidate for a durable prototype. Ask
the supplier to assess its actual dimensional capability, small-hole cleanup,
wall guidelines and finishing allowances. A PLA/PETG FDM or resin sample may
be useful for some checks, but cannot automatically qualify final PA12 fit,
surface friction, flexibility, toughness or anchor strength. Avoid assuming a
brittle presentation resin is suitable for an everyday keyring accessory.

Start **unpainted**. Terracotta/orange (`#C87558` shader base color, not a physical
color standard) and black eyes are visual intent only. Render lighting changes
the apparent shade. Agree a material sample or finish color with the printer.
Keep cavity/mating surfaces free of paint; coating buildup can consume the
nominal clearance. Readable rear lettering is already part of the lid mesh.

## Ask the printer to check

- Finished cavity tolerance against the nominal 0.35 mm normal offset, including
  shrinkage, surface roughness and any smoothing or coating.
- Minimum local walls, thin edges, eye floors, rear engraving and lid reliefs.
  Engraving is nominally 1 mm deep, with approximately 1 mm grid features.
- Ø4 mm diagonal keyring bore, rounded entries, usable ring articulation,
  print orientation and strength of the surrounding plastic.
- Whether any repair, resizing, thickening or support cleanup changes the fit.
  Obtain agreement before modifying the CAD or rescaling a part.

## Separate retention pads

Neither the outer body nor the separate lid has a qualified positive lock.
Bare rigid shells are clearance fits and remain unretained. v04 requires trial
compliant pads, supplied separately: two 8 × 8 mm body-side seats, two 8 × 5 mm
lid-side seats and one 16 × 7 mm lid-roof seat. These footprints are projected
dimensions on curved surfaces, not flattened cutting templates.

Seats have a nominal 0.65 mm normal gap to the visual device surrogate. Start
with supplier-approved soft, non-marking silicone foam or equivalent, using
0.80 mm uncompressed thickness only as an initial trial. Adhesive backing,
curvature, print tolerances and material compression all affect the fit. No pad
thickness, retention force or adhesive is physically qualified.

Pads initially bond to the cover and grip the device by friction. If lid
retention is insufficient, trial a finish-compatible removable double-sided
roof pad only after checking surface safety and removal. Do not use permanent
glue. Do not force a tight print onto the device, lever against its hinge, or
push through the USB-C port to remove it. Stop if it binds or scratches.

The five dark pad previews in the Blender file are illustrative seated envelopes,
not foam deformation simulations or printable hardware. See the
[v04 design notes](clawd-design-v04.md) for placement and caveats.

## Access and charging

The model includes geometric openings for front access and hinge movement.
The bottom-access update connects the original 14 × 8 mm USB-C window to the
two 6 × 4 mm side service windows by removing their intervening bridges.
Removing material can reduce local strength. Opening geometry is not evidence that
every plug, tap gesture or charging pad works. Qi / Apple Watch charging,
alignment and temperature need real-device checks. No magnets or conductive
inserts are specified. Hardware placement must not impede charging or scratch
the device.

Use [QUALIFICATION.md](QUALIFICATION.md) to record results before a finished
print. Vendor prices, lead times and acceptance are intentionally not asserted
in this public package.

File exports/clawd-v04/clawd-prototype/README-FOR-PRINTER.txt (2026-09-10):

CLAWD AIRPODS 4 ANC — v04 FULLER COVERAGE / PAD-RETENTION PROTOTYPE
10 September 2026. UNVALIDATED PHYSICAL PROTOTYPE; NOT A PRODUCTION RELEASE.

PRINT ONE BODY AND ONE LID, using either:
  clawd-prototype-body-v04-mm.stl
  clawd-prototype-lid-v04-mm.stl
OR:
  clawd-prototype-pair-v04-mm.3mf (contains both parts; not an extra pair)

UNITS: millimetres. Import STLs at 100%, one coordinate unit per mm.
3MF explicitly specifies millimetres. No automatic scaling, thickening or repair.
Expected bounding boxes:
  Body: 75.778 x 26.900 x 42.396 mm
  Lid:  62.000 x 26.900 x 16.504 mm
These are separate part bounds, not the assembled height.

CANDIDATE MATERIAL: unfilled MJF PA12, cleaned and unpainted for first fit testing.
Terracotta colour, black eyes, charcoal pads and metal ring in renders are
illustrative. Do not print a metal ring or the charcoal pad-preview geometry.
Keep dimensional fit surfaces uncoated for the first prototype.

REQUIRED SEPARATE HARDWARE, NOT IN THE PRINT FILES:
  Two compliant body-side pads, projected footprint 8 x 8 mm each.
  Two compliant lid-side pads, projected footprint 8 x 5 mm each.
  One compliant lid-roof pad, projected footprint 16 x 7 mm.
The seats follow curved surfaces; footprints are not flattened cutting patterns.
Nominal pad-seat clearance is 0.65 mm normal to the visual surrogate; the rest
of the cavity retains the provisional 0.35 mm clearance. Start by evaluating
0.80 mm soft, non-marking silicone foam or equivalent, including its backing.
Final pad material and thickness MUST follow printed-gap and retention tests.
Pads bond to the cover; a removable, finish-compatible double-sided roof pad
may be evaluated if friction alone is inadequate. No permanent glue.

THE BARE RIGID SHELLS ARE NOT SELF-RETAINING. No positive latch or retention
force is specified. Do not force the device in or use real AirPods for pull tests.

FEATURES TO REVIEW:
  Fuller rear skirts and shaped 0–115 degree surrogate hinge clearances.
  Bounded 10 x 7 mm front LED/pairing window.
  14 x 8 mm USB-C opening and two 6 x 4 mm speaker-access windows.
  Five recessed pad seats; approximately 2.10 mm minimum sampled roof backing.
  Existing 4 mm diagonal keyring bore with rounded entries.
  Existing 1 mm-deep pixel lettering.
The sampled backing value is NOT a global wall-thickness certification.
Service locations and cable access are provisional, not physically measured.
Completely depowder the cavities, recesses and bore. Flag inadequate walls or
unreachable cleaning areas before manufacture; do not silently modify them.

DIGITAL QA: watertight single-component meshes, positive volume, topology and
triangle-overlap screens, rigid-shell axial insertion, 116 sampled hinge poses
including seated pad previews, STL round trips and millimetre 3MF checks pass.
This is NOT proof of real fit, compliant-pad behaviour, retention, hinge travel,
acoustic access, charging performance, impact resistance or anchor strength.

Physically qualify device/cap retention, easy removal, full hinge movement,
earbud access, LED/pairing taps, USB-C, ANC speaker and wireless charging.
Do not suspend real AirPods from the ring until retention and anchor tests pass.

These v04 files have not been uploaded, quoted or accepted by a supplier.
Previous revision quotes or automatic statuses do not apply.
Design details: docs/clawd-design-v04.md in the project workspace.

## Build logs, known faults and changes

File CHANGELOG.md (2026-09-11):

# Changelog

## v04-bottom-access — 2026-09-11

Source and website update on top of v0.4.0-alpha; no new release tag.
**Physically unvalidated prototype.**

- Removed the two narrow bottom bridges, joining USB-C and side service windows.
- Matched the approved study geometry exactly; lid and all other meshes unchanged.
- Added current Blender, STL, 3MF and viewer files, reproducible patch/export
  script and digital validation report. Existing baseline files remain historical.
- Body remains manifold; all 18 sampled access rays pass. STL round trips confirm
  millimetre dimensions, and the 3MF contains two objects with explicit mm units.
- Replaced old downloads on Printables and Thingiverse, activated the new
  Sketchfab viewer, and retained existing uploaded gallery renders.
- Actual-device alignment, acoustics, cable clearance and strength remain untested.

## v0.4.0-alpha — 2026-09-10

Design v04 adds fuller coverage and explicit compliant-pad retention provisions.
**Physically unvalidated prototype, not a certified frictionless opening.**

- Deeper rear lid/body wrapping with shaped hinge-motion relief.
- Bounded 10 × 7 mm front window, separate 14 × 8 mm USB-C and two 6 × 4 mm
  speaker windows instead of the broad v03 cutouts.
- Five recessed seats for separately supplied compliant pads: two body-side,
  two lid-side and one roof seat. Bare rigid shells remain unretained.
- A 0.80 mm soft foam pad is a starting trial, not a validated fit specification.
- Preserved silhouette, pixel branding, 4 mm keyring bore and outer dimensions.
- 116 discrete hinge poses, 0–115° at 1° steps, pass the surrogate collision
  screen with seated-pad previews. No physical opening/friction test performed.
- Updated editable source, print exports, renders and digital reports. v03 files
  and the v0.3.0-alpha release remain available as historical artifacts.

## v0.3.0-alpha — 2026-09-09

First public source release, based on design revision v03. **Physically
unvalidated prototype.** The two manufacturing meshes match the private v03
prototype; preparing the public package is not a new fit or mechanical revision.

- Rounded Ø4 mm diagonal right-side keyring bore.
- Robust nominal 1 mm-deep pixel rear lettering, inherited from v02.
- Editable Blender source, JSON parameters, Python build/validation tools and
  explicitly dimensioned STL/3MF exports.
- Credited CC BY input assets and MIT / CC BY-SA project licensing.
- Non-open donor packages and hidden donor meshes excluded; clean reconstruction
  imports only the credited Clawd and AirPods sources.
- Separate printing guidance and physical-qualification checklist.

### Earlier construction stages

- v02: robust rear pixel lettering, without changing the fit cavity.
- v01: initial two-piece Clawd cover and provisional visual-model fit envelope.

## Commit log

2026-09-09 Publish open-source v03 physically unvalidated prototype
    [clawd-airpods4-anc-v03.blend, clawd-prototype-body-v03-mm.stl, clawd-prototype-lid-v03-mm.stl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]
2026-09-10 Release v04 fuller coverage and compliant-pad retention prototype
    [clawd-airpods4-anc-v04.blend, clawd-prototype-body-v04-mm.stl, clawd-prototype-lid-v04-mm.stl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]
2026-09-11 Update v04 bottom access and synchronize published CAD files
    [clawd-airpods4-anc-v04-bottom-access.blend, clawd-prototype-body-v04-bottom-access-mm.stl, clawd-prototype-lid-v04-bottom-access-mm.stl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]
